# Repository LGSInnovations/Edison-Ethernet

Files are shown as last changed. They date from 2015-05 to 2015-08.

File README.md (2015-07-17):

Edison Ethernet Block
=====================

This project gives the Intel Edison ethernet capibility in applications where wired connections are necessary or more reliable.

Currently, there are two common Linux distros used on the Intel Edison: Yocto Linux and Ubilinux. The Edison Ethernet project has support for both and is created from forking those distros.

## Distro Support ##

We currently support a Debian based distro, based on Ubilinux, and the Yocto distro. Both are built with the Yocto 3.10 kernel, bitbaked with driver support for the LAN9512/SMSC95xx USB-to-Ethernet chip.

#### Ubilinux/Debian ####

Popular for its familiar package manager (`apt-get`), this build has support for the Edison Ethernet block as well as support for MAC spoofing using a tool called [macchanger](https://github.com/alobbs/macchanger).

#### Yocto ####

This Linux distro is great for lightweight projects as it has a rootfs size of about 500MB. Although it has support for the Edison Ethernet block, it does not currently have easy support for MAC spoofing through macchanger.

## Installation and Setup ##

To start using the Edison Ethernet block, there are four options, increasing in time/difficulty:

1. Download the binary release of the `smsc95xx.ko` driver and add it to your kernel modules.
2. Download pre-packaged images of this project ready to flash with the smsc95xx.ko module baked in.
3. Clone the Edison-Ethernet git project to avoid using bitbake, but still allowing you flexibility to add/remove files from the rootfs. Build the debian or yocto image and then flash using `./flashall.sh` such as illustrated at the end of the guide [here](https://github.com/LGSInnovations/Edison-Ethernet/blob/master/guides/customize-yocto-kernel.md)
4. Build from source using `bitbake` and `menuconfig` and flash your device using `./flashall.sh`.

#### Option 1 - Binary Release ####

Download the release corresponding to your board. Extract the files.

Inside the release, there is a directory called `modules`. You'll find different kernel versions inside. To know which kernel module to install on your Edison, run `uname -r` and pick the corresponding directory inside the release. If your kernel version is not available, create an issue and we will release one for that version. You can also make your own by following [these](guides/version-magic-error.md) instructions.

Once you know which kernel version to use, follow [these](guides/installation.md) instructions to copy and install on your Edison.

#### Option 2 - Pre-packed Images ####

Download the release corresponding to your board. Extract the files.

Inside the release, there is a directory called `images`. You'll find two tarballs: `yocto.tar.gz` and `debian.tar.gz`. Extract your choice of distro and use `sudo ./flashall.sh` as normal.

#### Option 3 - Leverage This Project ####

See *Contributing to this Project* below.

#### Option 4 - Build from Source ####

Follow [these](guides) instructions. *Be aware that this will take at least 5+ hours.*

## Contributing to this Project ##

We use Git Submodules in our repo, if you've never used that tool before, make sure to read about it [here](https://git-scm.com/book/en/v2/Git-Tools-Submodules).

#### Development Environment ####

All developent must be on a Linux machine. Because of the naming convention of files in the decompressed rootfs of Linux, Mac OS and Windows will groan about invalid file names. We use [Ubuntu 14.04.02](http://releases.ubuntu.com/14.04/) for our host environment.

#### Getting the Source ####

Source code / files can be cloned as follows:

```bash
git clone --recursive https://github.com/LGSInnovations/Edison-Ethernet.git # The '--recursive' flag will also clone the submodules 
```

#### Packaging Your Changes ####

After you have changed things to your liking, use the `package.sh` script in `Edison-Ethernet/src/` to package your `edison-image-edison.ext4` rootfs so you can run `sudo ./flashall.sh`. Make sure that you have pulled in the latest changes in the `edison-debain-image` and/or `edison-yocto-image` submodules.

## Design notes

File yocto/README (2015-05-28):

This tutorial is to help build the full yocto kernel for the Intel Edison.  It is largely based on work done by
Shawn Hymel at: http://shawnhymel.com/585/creating-a-custom-linux-kernel-for-the-edison/

This step-by-step assumes you are on some newer version of Ubuntu, preferably 14.04 forward with access to the
internet and access to apt repositories.

Setup your environment:
sudo apt-get install build-essential git diffstat gawk chrpath texinfo libtool gcc-multilib

sudo apt-get install libqt4-core:i386 ligqt4-gui:i386

Setup git (if not already setup);
git config --global user.email "you@example.com"
git config --global user.name "Your Name"

1) Get the file at: http://downloadmirror.intel.com/24910/eng/edison-src-ww18-15.tgz
--> At a shell execute:  wget http://downloadmirror.intel.com/24910/eng/edison-src-ww18-15.tgz
--> You can also find the file at: https://downloadcenter.intel.com/SearchResult.aspx?lang=eng&keyword=edison
--> The file will likely be called edison-src-ww18-15.tgz

2) Once the file is downloaded extract the contents to your preferred workspace.
--> cd ~
--> tar xvzf edison-src-ww18-15.tgz

3) Go into the directory
--> cd ~/edison-src

Inside ~/edison-src should have a structure of:
-----------------------------------------------
you@yourcomputer:~ l
Makefile -> meta-intel-edison/utils/Makefile.mk
meta-intel-edison/
-----------------------------------------------

4) Setup the build tree by pulling source from remote repos
--> make setup

Inside ~/edison-src should now have a structure of:
bbcache
Makefile -> meta-intel-edison/utils/Makefile.mk
meta-intel-edison/
out/
pub/

5) source the shell environment [note this is for 64-bit linux builds!]
--> cd ~/edison-src/out/linux64
--> source poky/oe-init-build-env

* Some systems (mostly those behind a firewall) will have problems fetching some packages.  They are on the
github repo.  Download the directory and move the files to edison-src/bbcache/downloads.  make sure to return
to the right directory before baking your bits.

An example might be:
cp ~/Downloads/Edison-Ethernet/packages/* ~/edison-src/bbcache/downloads/
NOTE: Remove the README

6) bitbake your shiny new edison image.  This could take hours the first time.
--> bitbake edison-image

7) Configure the kernel with your new feature
--> bitbake linux-yocto -c menuconfig

8) use the menuconfig to add the LAN9512 that you need, or copy the .config file from the github repo.
If using the menuconfig you can navigate to the below <ESC> <ESC> goes back, <ENTER> goes forward, <SPACE>
selects.

Device Drivers --->
	[*] Network Device Support --->
		USB Network Adapters --->
			< >SMSC LAN95XX based USB 2.0 10/100 ethernet devices
		
Press <<space>> until you see a <*> for the SMSC LAN95XX. Save the configuration.

BTW, while you're in there you can add I2C support:
Device Drivers --->
	-*- I2C support --->
		I2C Hardware Bus support --->
			[ ] PMIC I2C Adapter

Press <<space>> until you see a <*> for the PMIC I2C Adapter. Save the configuration.

Exit out.

--> cp edison-src/out/linux64/build/tmp/work/edison-poky-linux/linux-yocto/3.10.17+gitAUTO*/linux-edison-standard-build/.config \\
	edison-src/meta-intel-edison/meta-intel-edison-bsp/recipes-kernel/linux/files/defconfig
	
9) bake your edison again
--> cd ~/edison-src/out/linux64
--> source poky/oe-init-build-env
--> bitbake edison-image

10) use your favorite text editor to edit postBuild.sh to the following:

line 9: build_dir=$top_repo_dir/out/linux64/build

or

execute the existing postBuild.sh with an argument that is the full path to the build dir

edison-src/meta-intel-edison/utils/flash/postBuild.sh edison-src/out/linux64/build

11) Your files will be ready in edison-src/out/linux64/build/toFlash

12) The edison kernel is in edison-image-edison.hddimg

13) If using ubilinux download their setup from: http://www.emutexlabs.com/ubilinux
--> Pick the ubilinux for Intel Edison or
--> wget http://www.emutexlabs.com/files/ubilinux/ubilinux-edison-150309.tar.gz

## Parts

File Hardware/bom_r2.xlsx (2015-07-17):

Qty | Value | Device | Package | Parts | Description | MF | MPN | Digikey Part Number | Mouser Part Number | Newark Part Number | URL | Price ea. | Price ea. Order | Final order qty
2 | 0 Ohm | R-US_R1210 | R1210 | R10, R16 | RESISTOR, American symbol | Vishay | CRCW12100000Z0EA |  |  | 72M6870 | http://www.newark.com/vishay-dale/crcw12100000z0ea/resistor-chip-jumper-zero-ohm/dp/72M6870?ost=72M6870 | 0.248 | 0.496 | 10
1 | 0.01uF | C-USC0603K | C0603K | C18 | CAPACITOR | AVX | 06035C103KAT2A |  |  | 36K3729 | http://www.newark.com/avx/06035c103kat2a/ceramic-capacitor-0-01uf-50v-x7r/dp/36K3729?ost=36K3729 | 0.002 | 0.002 | 5
1 | 0.022uF | C-USC0805 | C0805 | C23 | CAPACITOR | AVX | 08055C223KAT2A |  |  | 35K2132 | http://www.newark.com/avx/08055c223kat2a/ceramic-capacitor-0-022uf-50v/dp/35K2132?ost=35K2132 | 0.162 | 0.162 | 5
15 | 0.1uF | C-USC0402K | C0402K | C1, C2, C3, C4, C5, C6, C7, C8, C9, C10, C11, C12, C14, C15, C16 | CAPACITOR | AVX | 0402ZD104KAT2A |  |  | 96M1117 | http://www.newark.com/avx/0402zd104kat2a/ceramic-capacitor-0-1uf-10v-x5r/dp/96M1117?ost=96M1117 | 0.006 | 0.09 | 75
2 | 1uF | C-USC0402K | C0402K | C13, C27 | CAPACITOR | AVX | 0402ZD105KAT2A |  |  | 06M4041 | http://www.newark.com/avx/0402zd105kat2a/ceramic-capacitor-1uf-10v-x5r/dp/06M4041?ost=06M4041 | 0.24 | 0.48 | 10
1 | 10 Ohm | R-US_R0402 | R0402 | R9 | RESISTOR | Multicomp | MC00625W0402110R |  |  | 58K4201 | http://www.newark.com/multicomp/mc00625w0402110r/resistor-10r-0-063w-1-0402/dp/58K4201?ost=58K4201 | 0.002 | 0.002 | 5
2 | 10K | R-US_R0603 | R0603 | R1, R4, R17 | RESISTOR | Multicomp | MCMR06X1002FTL |  |  | 86T3506 | http://www.newark.com/multicomp/mcmr06x1002ftl/resistor-ceramic-10k-0-1w-1/dp/86T3506 | 0.016 | 0.032 | 10
1 | 12.4K | R-US_R0603 | R0603 | R3 | RESISTOR | Multicomp | MC0063W0603112K4 |  |  | 94W4696 | http://www.newark.com/multicomp/mc0063w0603112k4/resistor-12k4-0-063w-1-0603/dp/94W4696?ost=94W4696 | 0.001 | 0.001 | 5
1 | 56K | R-US_R0 | R0603 | R15 | RESISTOR | Panasonic | ERJ-P03F5602V |  |  | 05X8647 | http://www.newark.com/panasonic-electronic-components/erj-p03f5602v/thick-film-resistor-56kohm-1-0603/dp/05X8647 | 0.031 | 0.031 | 5
1 | 12K | R-US_R0603 | R0603 | R2 | RESISTOR | Multicomp | MC0603SAF1202T5E |  |  | 79M5909 | http://www.newark.com/multicomp/mc0603saf1202t5e/thick-film-resistor-12kohm-100mw/dp/79M5909?ost=79M5909 | 0.067 | 0.067 | 5
1 | 150uF | CAP_POLE | PANASONIC_E | C26 | Capacitor Polarized | Panasonic | EEH-ZC1V151P |  |  | 91T4915 | http://www.newark.com/panasonic-electronic-components/eeh-zc1v151p/aluminum-electrolytic-capacitor/dp/91T4915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 | 3.39 | 3.39 | 5
4 | 15pF | C-USC0402 | C0402 | C19, C20, C21, C22 | CAPACITOR | AVX | 04025A150JAT2A |  |  | 96M1134 | http://www.newark.com/avx/04025a150jat2a/ceramic-capacitor-15pf-50v-c0g/dp/96M1134?ost=96M1134 | 0.002 | 0.008 | 20
1 | 1M | R-US_R0402 | R0402 | R14 | RESISTOR | Multicomp | MC00625W040211M |  |  | 58K4211 | http://www.newark.com/multicomp/mc00625w040211m/resistor-1m-0-063w-1-0402/dp/58K4211?ost=58K4211 | 0.001 | 0.001 | 5
2 | 2.0A 120Ohm | L-US0603 | L0603 | L1, L2 | Ferrite Bead | Murata | BLM18PG121SN1D |  |  | 73M9109 | http://www.newark.com/murata/blm18pg121sn1d/ferrite-bead-120-ohm-2a-0603/dp/73M9109?ost=73M9109 | 0.044 | 0.088 | 10
1 | 25MHz | CRYSTAL-GROUNDED | CRYSTAL-SMD-5X3 | U$1 | 25MHz Crystal | Abracon | ABM3B-25.000MHZ-B2-T |  |  | 13J1745 | http://www.newark.com/abracon/abm3b-25-000mhz-b2-t/crystal-25mhz-18pf-5-x-3-2mm/dp/13J1745?ost=13J1745 | 0.691 | 0.691 | 5
3 | 330 Ohm | R-US_R0402 | R0402 | R11, R12, R13 | RESISTOR | Multicomp | MC00625W04021330R |  |  | 58K4323 | http://www.newark.com/multicomp/mc00625w04021330r/resistor-330r-0-063w-1-0402/dp/58K4323?ost=58K4323 | 0.067 | 0.201 | 15
2 | 33pF | C-USC0402 | C0402 | C24, C25 | CAPACITOR | AVX | 04025A330JAT2A |  |  | 96M1150 | http://www.newark.com/avx/04025a330jat2a/ceramic-capacitor-33pf-50v-c0g/dp/96M1150?ost=96M1150 | 0.11 | 0.22 | 10
1 | 4.7uF | C-USC0603K | C0603K | C17 | CAPACITOR | AVX | 06036D475KAT2A |  |  | 96M1295 | http://www.newark.com/avx/06036d475kat2a/ceramic-capacitor-4-7uf-6-3v-x5r/dp/96M1295?ost=96M1295 | 0.013 | 0.013 | 5
4 | 49.9 Ohm | R-US_R0402 | R0402 | R5, R6, R7, R8 | RESISTOR | Multicomp | MC0402WGF499JTCE |  |  | 79M5889 | http://www.newark.com/multicomp/mc0402wgf499jtce/thick-film-resistor-49-9-ohm-63mw/dp/79M5889?ost=79M5889 | 0.067 | 0.268 | 20
1 | EDISON_CONNECTOR_FULLHEADER | Edison Plug (Male) | DF40C-70DP-0.4(51) | U4 |  | Hirose | DF40C-70DP-0.4V(51) | H11630CT-ND |  |  | http://www.digikey.com/product-search/en?KeyWords=H11630CT-ND&WT.z_header=search_go | 1.44 | 1.44 | 5
1 | EDISON_CONNECTOR_FULLMOUNTING_HOLES | Hirose Socket (Female) | DF40C(2.0)-70DS-0.4V(51) | U1 |  | Hirose | DF40C(2.0)-70DS-0.4V(51) | H11908CT-ND |  | 68X2583 | http://www.digikey.com/product-search/en?KeyWords=H11908CT-ND&WT.z_header=search_go | 1.37 | 1.37 | 5
1 | Green LED | LEDCHIP-LED0805 | CHIP-LED0805 | LED1 | LED | Lite-On | LTST-C170GKT/SML-LX0805SGC-TR | 160-1179-1-ND |  | 09J9138 | http://www.newark.com/lumex/sml-lx0805sgc-tr/led-green-1-25mm-x-1-4mm-15mcd/dp/09J9138?ost=09J9138 | 0.093 | 0.093 | 5
1 | J1011F01P | J1011F01P | J1 | X1 | PULSEJACK (TM) 1x1 Tab-UP RJ45 with Integrated Magnetics | Pulse Engineering | J1011F01PNL | 553-1350-ND |  |  | http://www.digikey.com/product-search/en?KeyWords=553-1350-ND&WT.z_header=search_go | 7.87 | 7.87 | 5
1 | LAN9512-JZX | LAN9512-JZX | QFN50P900X900X100-65N | U2 | IC, USB2 - ENET CNTRL 2-PORT HUB, 64VQFN | Microchip/SMSC | LAN9512-JZX | 638-1086-ND |  | 66W1988 | http://www.newark.com/microchip/lan9512-jzx/usb-hub-ethernet-controller-100mbps/dp/69W9521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 | 4.72 | 4.72 | 5
1 | MAX4495AAUT | MAX4995 | SOT23 | U3 | IC, Current-limited USB control switch | Maxim | MAX4995A |  | 700-MAX4995AAUTT |  | http://www.mouser.com/ProductDetail/Maxim-Integrated/MAX4995AAUT+T/ | 2.75 | 2.75 | 5
1 | USB-A-S | USB-A-S | USB-A-S | JP2, | USB Connectors | FCI | 87583-2010BLF |  |  | 31M6798 | http://www.newark.com/fci/87583-2010blf/usb-2-0-type-a-recetpacle-smt/dp/31M6798?ost=31M6798 | 0.696 | 0.696 | 5
 |  |  |  |  |  |  |  |  |  |  |  | Price Ea. Order: | 25.182
 |  |  |  |  |  |  |  |  |  |  |  | # of Orders: | 5
 |  |  |  |  |  |  |  |  |  |  |  | Final Order Cost: | 125.91

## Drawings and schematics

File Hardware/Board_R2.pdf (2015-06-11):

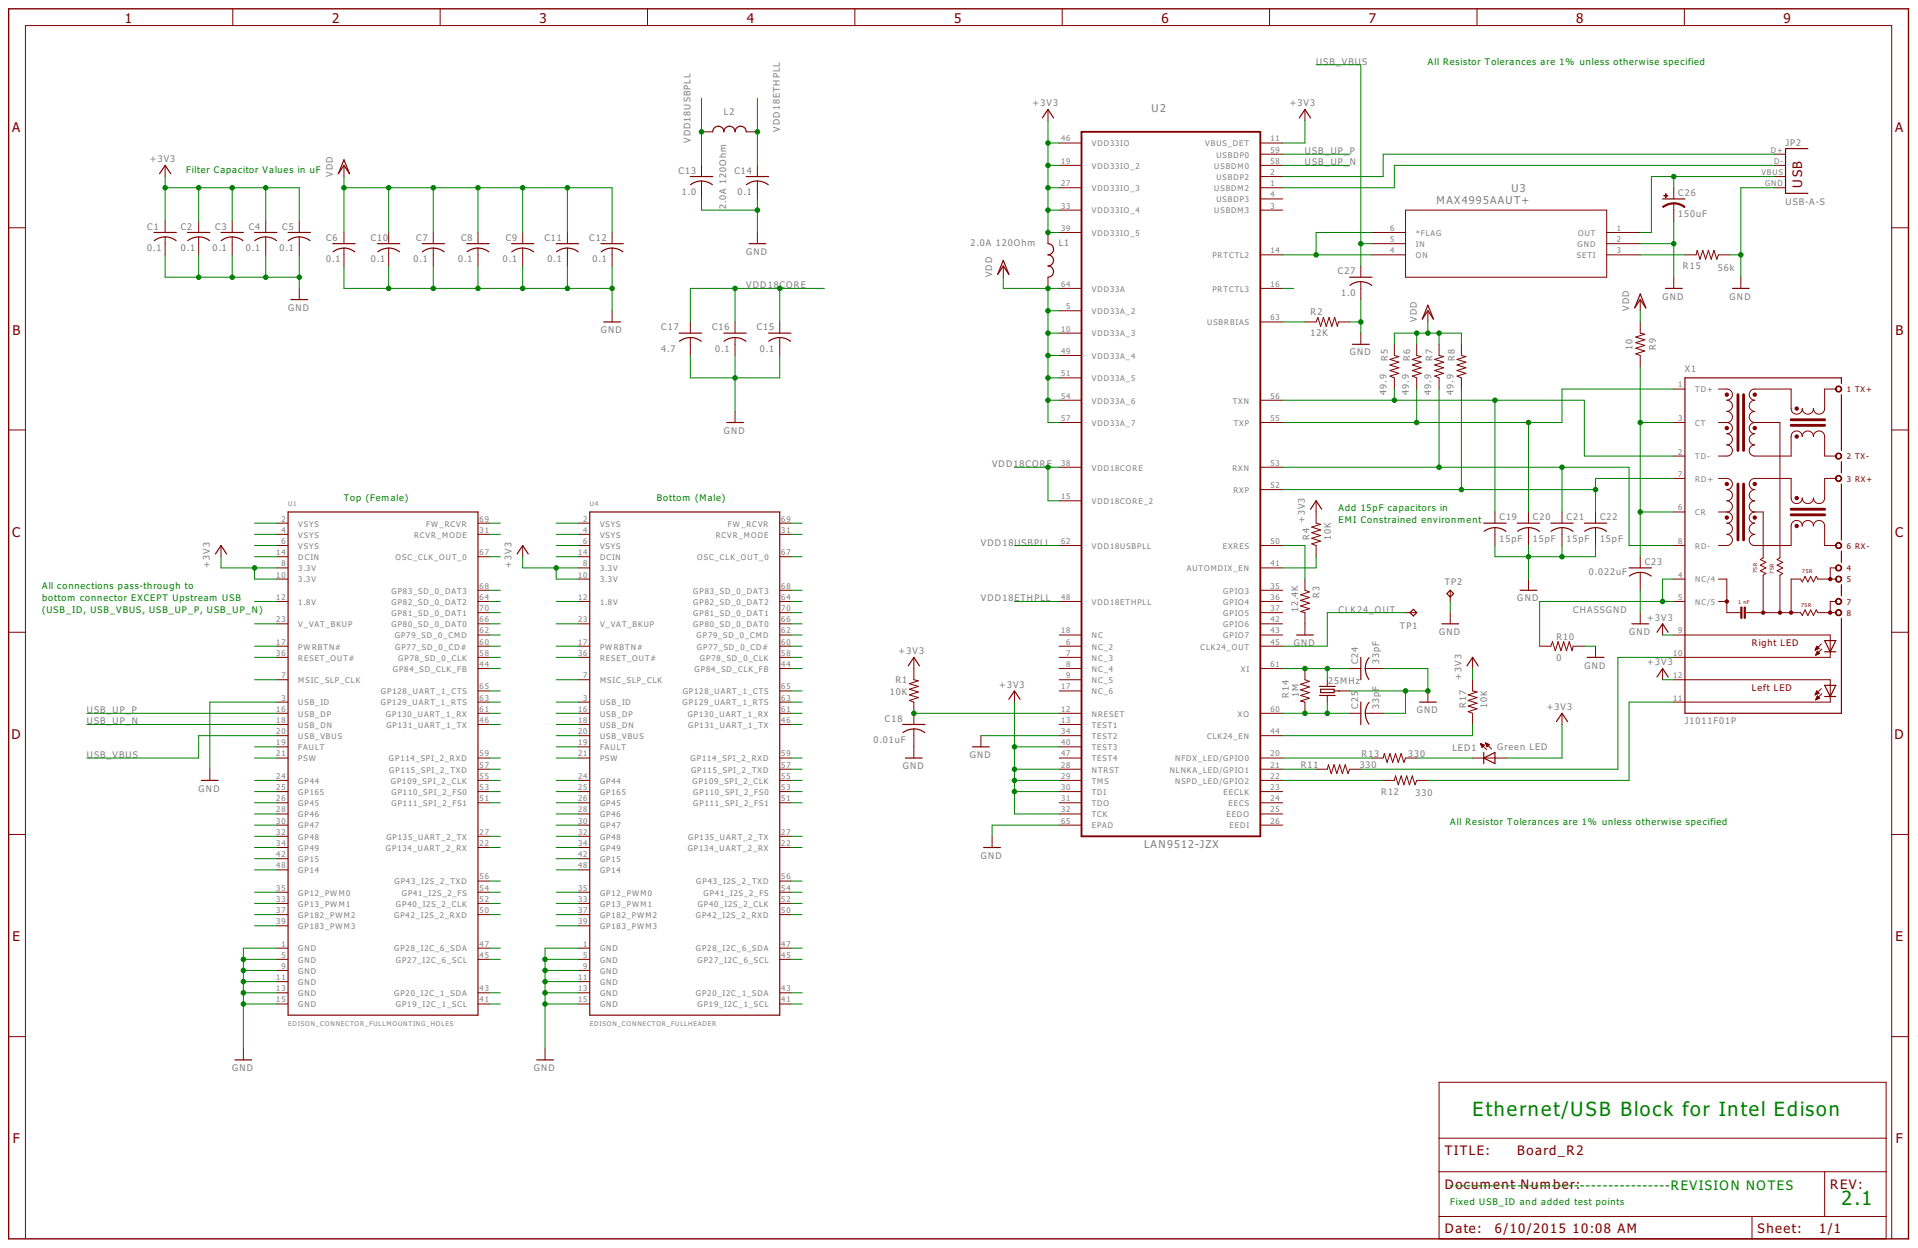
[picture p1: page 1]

All Resistor Tolerances are 1% unless otherwise specified

Filter Capacitor Values in uF

33 | 4 3 USBDP3

Add 15pF capacitors in EMI Constrained environment All connections pass-through to bottom connector EXCEPT Upstream USB

Ethernet/USB Block for Intel Edison

REV: TITLE: Document Number: Board_R2

---------------------------------------REVISION NOTES Fixed USB_ID and added test points | 2.1

Date: 6/10/2015 10:08 AM | Sheet: 1/1

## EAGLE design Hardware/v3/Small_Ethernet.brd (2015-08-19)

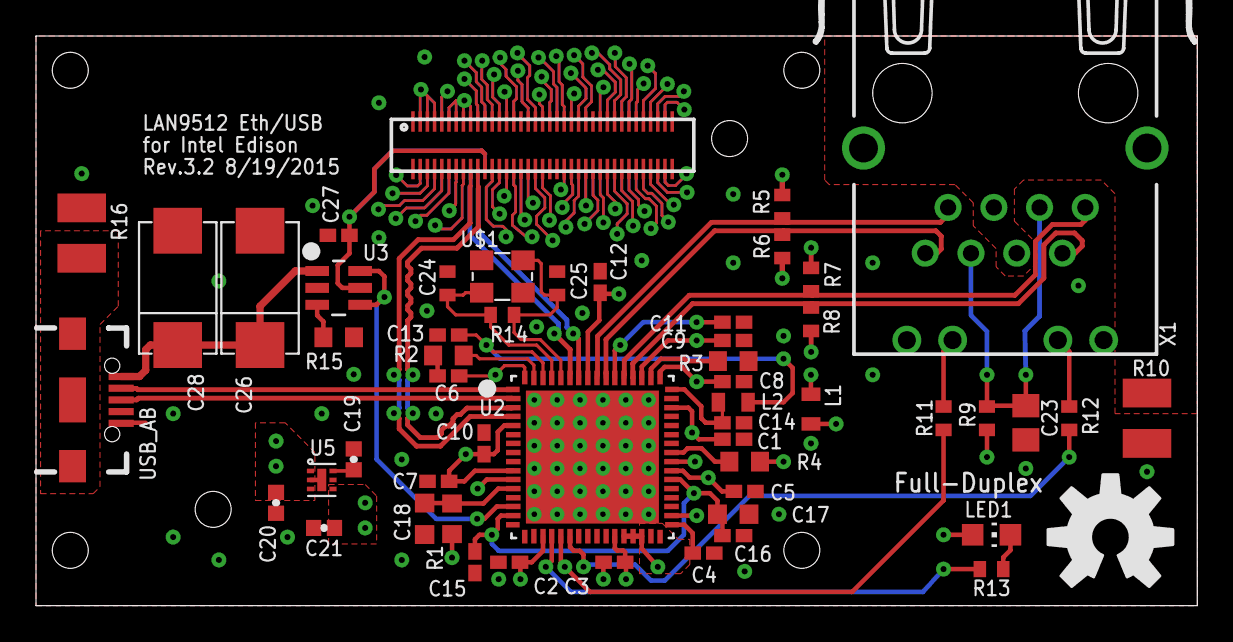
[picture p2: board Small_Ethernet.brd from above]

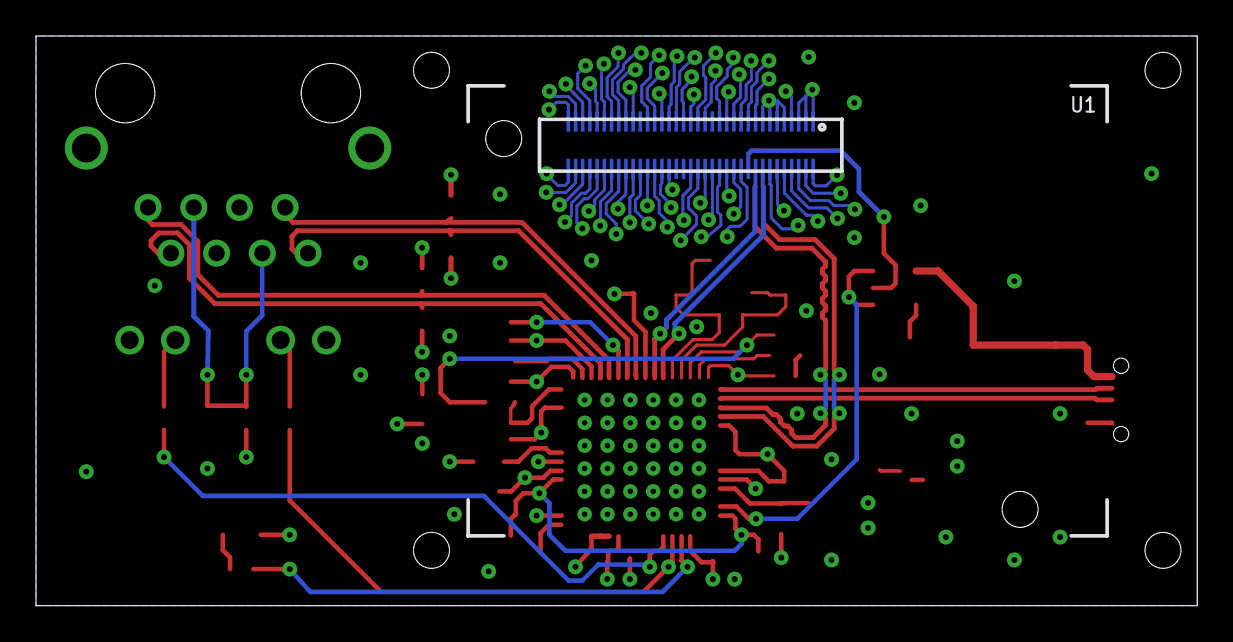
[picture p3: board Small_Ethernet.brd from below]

Board: 4 copper layers, 64.5 x 31.6 mm, 55 parts (2 on the bottom side), 90 nets.

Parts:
C1, C2, C3, C4, C5, C6, C7, C8, C9, C10, C11, C12, C14, C15, C16: 0.1; C0402K
C13, C27: 1.0; C0402K
C17: 4.7; C0603K
C18: 0.01uF; C0603K
C19: .1uF; 0402-CAP
C20, C21: 1uF; 0402-CAP
C23: 0.022uF; C0805
C24, C25: 33pF; C0402
C26, C28: CAP-2917
E$2: OSHW-LOGO-L
L1, L2: 2.0A 120Ohm; L0603
LED1: Green LED; CHIP-LED0805
R1, R4: 10K; R0603
R2: 12K; R0603
R3: 12.4K; R0603
R5, R6, R7, R8: 49.9; R0402
R9: 10; R0402
R10, R16: 0; R1210
R11, R12, R13: 330; R0402
R14: 1M; R0402
R15: 56k; R0603
U1: EDISON_CONNECTOR_FULLMOUNTING_HOLES; EDISON_DAUGHTER
U2: LAN9512-JZX; QFN50P900X900X100-65N
U3: MAX4995AAUT+; 21-0058I
U4: EDISON_CONNECTOR_FULLHEADER; DF40C-70DP-0.4(51)
U5: 6-UFDFN
U$1: SMDCRYSTAL_3.2X2.5
USB_AB: USB-AB-MICRO-SMD_V03
X1: J1011F01P; J1

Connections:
BYP: C19.1, U5.P6
DSUSB_N: U2.1, USB_AB.D-1
DSUSB_P: U2.2, USB_AB.D+1
GND: C1.2, C2.2, C3.2, C4.2, C5.2, C6.2, C7.2, C8.2, C9.2, C10.2, C11.2, C12.2, C13.2, C14.2, C15.2, C16.2, C17.2, C18.2, C19.2, C20.1, C21.2, C23.2, C24.2, C25.2, C26.NEG, C27.2, C28.NEG, R2.2, R3.2, R10.2, R15.1, R16.2, U1.1, U1.3, U1.5, U1.9, U1.11, U1.13, U1.15, U2.34, U3.2, U4.1, U4.3, U4.5, U4.9, U4.11, U4.13, U4.15, U5.GND, U5.P2, U$1.P2_GND, U$1.P4_GND, USB_AB.GND1
GP28_I2C_6_SDA: U1.47, U4.47
unnamed: C13.1, L2.1, U2.62
unnamed: C14.1, L2.2, U2.48
unnamed: C15.1, C16.1, C17.1, U2.15, U2.38
unnamed: R2.1, U2.63
unnamed: C18.1, R1.1, U2.12
unnamed: R3.1, U2.50
unnamed: R4.1, U2.41
unnamed: C23.1, R9.1, X1.3, X1.6
unnamed: R11.2, U2.21
unnamed: R11.1, X1.10
unnamed: R12.1, X1.11
unnamed: R12.2, U2.22
unnamed: LED1.C, R13.1
unnamed: R13.2, U2.20
unnamed: C24.1, R14.1, U2.61, U$1.P1_I/O
unnamed: C25.1, R14.2, U2.60, U$1.P3_O/I
unnamed: U2.14, U3.4, U3.6
unnamed: R15.2, U3.3
P7: U1.7, U4.7
P12: U1.12, U4.12
P14: U1.14, U4.14
P17: U1.17, U4.17
P19: U1.19, U4.19
P21: U1.21, U4.21
P22: U1.22, U4.22
P23: U1.23, U4.23
P24: U1.24, U4.24
P25: U1.25, U4.25
P26: U1.26, U4.26
P27: U1.27, U4.27
P28: U1.28, U4.28
P30: U1.30, U4.30
P31: U1.31, U4.31
P32: U1.32, U4.32
P33: U1.33, U4.33
P34: U1.34, U4.34
P35: U1.35, U4.35
P36: U1.36, U4.36
P37: U1.37, U4.37
P39: U1.39, U4.39
P41: U1.41, U4.41
P42: U1.42, U4.42
P43: U1.43, U4.43
P44: U1.44, U4.44
P45: U1.45, U4.45
P46: U1.46, U4.46
P48: U1.48, U4.48
P50: U1.50, U4.50
P51: U1.51, U4.51
P52: U1.52, U4.52
P53: U1.53, U4.53
P54: U1.54, U4.54
P55: U1.55, U4.55
P56: U1.56, U4.56
P57: U1.57, U4.57
P58: U1.58, U4.58
P59: U1.59, U4.59
P60: U1.60, U4.60
P61: U1.61, U4.61
P62: U1.62, U4.62
P63: U1.63, U4.63
P64: U1.64, U4.64
P65: U1.65, U4.65
P66: U1.66, U4.66
P67: U1.67, U4.67
P68: U1.68, U4.68
P69: U1.69, U4.69
P70: U1.70, U4.70
RX_N: R8.1, U2.52, X1.7
RX_P: R7.1, U2.53, X1.8
S$5: U1.10, U4.10
S$6: U1.8, U4.8
SHLD: R10.1, X1.4, X1.5, X1.M1, X1.M2
TX_N: R5.1, U2.56, X1.2
TX_P: R6.1, U2.55, X1.1
USBSHLD: R16.1, USB_AB.SHIELD1, USB_AB.SHIELD2, USB_AB.SHIELD3
USBUP_N: U1.18, U2.58
USBUP_P: U1.16, U2.59
USB_D_N: U2.3, U4.18
USB_D_P: U2.4, U4.16
USB_VBUS: C27.1, U1.20, U3.5, U4.20
VBUS_OUT: C26.POS, C28.POS, U3.1, USB_AB.VBUS1
VDD3IO: C1.1, C2.1, C3.1, C4.1, C5.1, C21.1, L1.1, LED1.A, R1.2, R4.2, U2.11, U2.19, U2.27, U2.28, U2.29, U2.30, U2.32, U2.33, U2.39, U2.40, U2.46, U5.P4, X1.9, X1.12
VDD33A: C6.1, C7.1, C8.1, C9.1, C10.1, C11.1, C12.1, L1.2, R5.2, R6.2, R7.2, R8.2, R9.2, U2.5, U2.10, U2.49, U2.51, U2.54, U2.57, U2.64
VSYS: C20.2, U1.2, U1.4, U1.6, U4.2, U4.4, U4.6, U5.P1, U5.P3

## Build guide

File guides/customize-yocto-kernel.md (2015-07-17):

Customizing the Yocto Kernel
============================

This tutorial is to help build the full Yocto Kernel for the Intel Edison.  It is largely based on work done by [Shawn Hymel](http://shawnhymel.com/585/creating-a-custom-linux-kernel-for-the-edison/).

This step-by-step assumes you are on some newer version of Ubuntu as the host machine, preferably 14.04 forward with access to the internet and access to apt repositories.

**Note:** The build part of this tutorial can take up to 4 hours.

##Setting Up Your Environment##

1. Install Dependencies:
	```bash
	sudo apt-get install build-essential git diffstat gawk chrpath texinfo libtool gcc-multilib libsdl1.2-dev dfu-util libqt4-core:i386 libqt4-gui:i386
	```

2. Setup git (if not already setup):
	```bash
	git config --global user.email "you@example.com"
	git config --global user.name "Your Name"
	```

##Building the Yocto Kernel:##

1. Get the file at: http://downloadmirror.intel.com/24910/eng/edison-src-ww18-15.tgz
	- At a shell execute:  `wget http://downloadmirror.intel.com/24910/eng/edison-src-ww18-15.tgz` in your home folder.
	- You can also find the file at: https://downloadcenter.intel.com/SearchResult.aspx?lang=eng&keyword=edison
	- The file will likely be called `edison-src-ww18-15.tgz`

2. Once the file is downloaded extract the contents to your preferred workspace.
	```bash
	cd ~
	tar xvzf edison-src-ww18-15.tgz
	```

3. Go into the directory `~/edison-src`:
	```bash
	cd ~/edison-src
	```

 It should have a structure of:
	```bash
	.
	+-- Makefile -> meta-intel-edison/utils/Makefile.mk
	+-- meta-intel-edison/
	```

4. Setup the build tree by pulling source from remote repos
	```bash
	make setup
	```

 Now, `~/edison-src` should now have a structure of:
	```bash
	.
	+-- bbcache/
	+-- Makefile -> meta-intel-edison/utils/Makefile.mk
	+-- meta-intel-edison/
	+-- out/
	+-- pub/
	```

 *5. Some systems (mostly those behind a firewall) will have problems fetching some packages.  They are on in this repo at `Edison-Ethernet/packages/`.  Download the directory and move the files to `~/edison-src/bbcache/downloads`.*

 An example of downloading these packages from the repo might be:
	```bash
	cp ~/Edison-Ethernet/packages/* ~/edison-src/bbcache/downloads/
	```
	**NOTE**: Remove the README (`rm ~/edison-src/bbcache/downloads/README`)

6. bitbake your shiny new edison image.  **This could take hours the first time.** This can be done in two ways:
	1. Sourcing the shell environment and then running `bitbake`.

		 ```bash
		 cd ~/edison-src/out/linux64
		 source poky/oe-init-build-env
		 ```
		 This will automatically put you in the `~/edison-src/build` directory. Then run:
		 ```bash
		 bitbake edison-image
		 ```
	2. Using the Makefile. *(make sure you are in the `~/edison-src` directory).*

		 **Option 2:** 
		 ```bash
		 make image
		 ```

		 **NOTE**: If your bitbake fails, (possibly with `swig-3.0.5` not being found) just run `make image` again, and it will start from there.

After a number of hours (e.g., 4 or 5) come back to configure the kernel.

----------------------------------------------------------------------

##Configuring the Kernel##

1. Configure the kernel with your new feature (this may take some time):
	```bash
	source ~/edison-src/out/linux64/poky/oe-init-build-env
	bitbake linux-yocto -c menuconfig
	```

2. Use the `menuconfig` to add the LAN9512 that you need, or copy the `.config` file from this repo. If using the `menuconfig` you can navigate to the below <kbd>esc</kbd> <kbd>esc</kbd> goes back, <kbd>enter</kbd> goes forward, <kbd>space</kbd> selects.

	```
	Device Drivers --->
		[*] Network Device Support --->
			USB Network Adapters --->
				< >SMSC LAN95XX based USB 2.0 10/100 ethernet devices
	```
		
 	Press <kbd>space</kbd> until you see a <*> for the SMSC LAN95XX. Save the configuration.

	Also, while you're in there you can add I2C support:
	```
	Device Drivers --->
		-*- I2C support --->
			I2C Hardware Bus support --->
				[ ] PMIC I2C Adapter
	```

	Press <kbd>space</kbd> until you see a <*> for the PMIC I2C Adapter. Save the configuration.

	Exit out.
	```bash
	cp edison-src/out/linux64/build/tmp/work/edison-poky-linux/linux-yocto/3.10.17+gitAUTO*/linux-edison-standard-build/.config \\
	edison-src/meta-intel-edison/meta-intel-edison-bsp/recipes-kernel/linux/files/defconfig
	```
	
3. Bake your Edison again, either using `make` or `bitbake` as above.
	```
	cd ~/edison-src
	make
	```

	or

	```bash
	cd ~/edison-src/out/linux64
	source poky/oe-init-build-env
	bitbake edison-image
	```

4. Run the `postBuild.sh` script to clean up the `toFlash` directory as follows:

	```bash
	~/edison-src/meta-intel-edison/utils/flash/postBuild.sh ~/edison-src/out/linux64/build
	```

	Alternatively, you can use your favorite text editor to edit `postBuild.sh` to the following:
	```bash
	line 9: build_dir=$top_repo_dir/out/linux64/build
	```

	And then execute the `postBuild.sh` script without the build directory argument:
	```bash
	~/edison-src/meta-intel-edison/utils/flash/postBuild.sh
	```

5. Your files will be ready in `~/edison-src/out/linux64/build/toFlash`.

6. You may now either flash your Edison with Yocto and follow the Yocto Network Interface setup, or you can use the Yocto kernel in the Ubilinux distro to give yourself a more fleshed out Linux distro with `apt-get`.

7. Flashing your Edison with Yocto:
	
	```bash
	sudo ~/edison-src/out/linux64/build/toFlash/flashall.sh
	```

	And then plug your Edison in via the OTG port of the SparkFun base-board.

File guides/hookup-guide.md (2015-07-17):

Hookup Guide for LAN9512 Ethernet block
=======================================

##Plug in the Board##
Once you have [installed support for the SMSC LAN9512](https://github.com/LGSInnovations/Edison-Ethernet/blob/master/README.md) on your Intel Edison, you may connect the Edison blocks together. While connecting and using the hardware, keep the following points in mind: 
* When operating properly, the "Full-Duplex" LED on the Ethernet block will be illuminated. 
* Blocks can be stacked without any sort of mounting hardware. However, this can cause undue mechanical stress on the connectors. To alleviate this, use hardware such as that found in the [Sparkfun Edison Hardware Pack](https://www.sparkfun.com/products/13187) to securely mount your Edison blocks.
* The SMSC LAN9512 communicates with the Intel Edison over USB-OTG. Do not connect any other blocks that use the Intel Edison's USB-OTG capability. Disconnect the Ethernet block when flashing your Edison's firmware. 
* The Ethernet block cannot power the Edison. A power source such as the [Sparkfun Base Block](https://www.sparkfun.com/products/13045) in your block stack is required. 
* If an overcurrent condition is detected in a device connected to the downstream USB port on the Ethernet Block, the port will be shut down. Usually, the port will reset itself after a few seconds. In some circumstances, you may need to completely power-down the Ethernet Block and re-apply power to reset the port. 
* Version 1.0 of the Ethernet block is too wide to accomodate a USB cable plugged into a board such as the Sparkfun Base Block if the Base Block and the Ethernet Block are right next to each other in your block stack. To remedy this, connect a block with no external connectors (such as an empty [Sparkfun GPIO block](https://www.sparkfun.com/products/13038)) between the Base Block and the Ethernet Block. 
* Version 1.0 of the Ethernet Block operates close to the maximum current supply capacity of the 3.3V rails of the Intel Edison. Use caution when connecting blocks that use the 3.3V rails and power them with an external 3.3V supply if possible.

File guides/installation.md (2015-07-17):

Installing the smsc95xx.ko Module
=================================

These steps can be used after (1) downloading the release binaries, or (2) building your own modules from source.

## Getting the Module to the Edison ##

There are three ways to get the module onto the Edison:

1. Use WiFi and `curl`
2. Use a USB drive.
3. Access the Edison's mass-storage. **[Yocto only!]**

#### Using WiFi ####

If not already done, enable Edison's WiFi using the appropriate guide:

+ [Yocto](https://software.intel.com/en-us/connecting-your-intel-edison-board-using-wifi)
+ [Debian](https://learn.sparkfun.com/tutorials/loading-debian-ubilinux-on-the-edison#enable-wifi)

Use a service such as [transfer.sh](https://transfer.sh/) to `curl` the `smsc95xx.ko` module from your host machine to the Intel Edison.

You should now have the `smsc95xx.ko` in your home folder.

#### USB Drive ####

Copy the `smsc95xx.ko` module from your host machine to a usb drive.

Use a guide (like [this](http://linuxconfig.org/howto-mount-usb-drive-in-linux) one) to mount the USB drive. 

*Remember that you might have to format the drive as FAT32 before you use it.*

#### Edison's Mass-Storage [Yocto only!] ####

This will only work for Yocto, but you can plug the Edison to your host machine through the OTG port and it will show up as a mass-storage device that you can drag the `smsc95xx.ko` file onto.

Then use these steps on your Edison to access the partition:

```bash
rmmod g_multi
mkdir /update
losetup -o 8192 /dev/loop0 /dev/disk/by-partlabel/update
mount /dev/loop0 /update
```

*see [this](https://communities.intel.com/message/253856#253856) answer*

## Installing the Module on the Edison ##

Now that you have the module on the Edison, we need to install it so the kernel knows where to find it.

Use the following commands:

```bash
# Create a logical place to store it in the kernel dir
mkdir -p /lib/modules/$(uname -r)/kernel/drivers/net/usb

# Move the module to that directory
mv smsc95xx.ko /lib/modules/$(uname -r)/kernel/drivers/net/usb/

# Probe all modules to generate the modules.dep and map files
# This allows you to run `modprobe smsc95xx` from anywhere.
# This also allows the system to bring up the LAN chip on boot.
depmod -a

# Enable the driver
modprobe smsc95xx
```

You should now see the `smsc95xx` module in the `lsmod` list.

Similarly, running `lsusb` should show something like:

```bash
Bus 001 Device 003: ID 0424:ec00 Standard Microsystems Corp. SMSC9512/9514 Fast Ethernet Adapter
Bus 002 Device 001: ID 1d6b:0003 Linux Foundation 3.0 root hub
Bus 001 Device 002: ID 0424:9512 Standard Microsystems Corp. LAN9500 Ethernet 10/100 Adapter / SMSC9512/9514 Hub
Bus 001 Device 001: ID 1d6b:0002 Linux Foundation 2.0 root hub
```

If the Ethernet is plugged in, you should see the Full-Duplex LED light up on the board.

## Setting up the Network Interface ##

Follow the appropriate guide to set up your Network Inferface:
	
+ [Yocto](yocto-network-setup.md)
+ [Debian](ubilinux-network-setup.md)

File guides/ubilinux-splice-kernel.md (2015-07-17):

Using the Customized Yocto Kernel in Ubilinux
=============================================

After having BitBaked the Yocto Kernel with SMSC LAN95XX driver support for the Ethernet block, you can take the Yocto kernel and its modules and splice them into the Ubilinux distro.

This allows you to use the LAN9512 Ethernet block with a Debian-based Linux distro, with better support for installing packages.

1. Download the Ubilinux distro from [here](http://www.emutexlabs.com/ubilinux). Choose the Intel Edison.
	- Alternatively, run `wget http://www.emutexlabs.com/files/ubilinux/ubilinux-edison-150309.tar.gz` on your Linux host machine.

2. Extract the archive with:
	
	```bash
	tar xvf ~/ubilinux-edison-150309.tar.gz
	cd ubilinux-150309/toFlash
	```

3. The Edison kernel is in `edison-image-edison.hddimg`, the filesystem is in `edison-image-edison.ext4`. Move the kernel (`*.hddimg`) out of the directory:

	```bash
	mv edison-image-edison.hddimg ../edison-image-edison.hddimg.ubi
	```

4. Copy the Yocto Edison kernel to here:

	```bash
	cp ~/edison-src/out/current/build/toFlash/edison-image-edison.hddimg .
	```

5. Next, you will need to mount the Ubilinux filesystem and replace its kernel modules with the Yocto kernel modules:

	```bash
	sudo mkdir /mnt/ubi
	sudo mount edison-image-edison.ext4 /mnt/ubi
	sudo rm -rf /mnt/ubi/lib/modules/3.10.17-yocto-standard-r2
	sudo cp -r ~/edison-src/out/current/build/tmp/work/edison-poky-linux/edison-image/1.0-r0/rootfs/lib/modules/* /mnt/ubi/lib/modules/
	sudo umount /mnt/ubi
	```
6. Now that you've copied the Yocto kernel and its modules, you can flash your Edison as follows:

	```bash
	cd ~/ubilinux-150309/toFlash
	sudo ./flashall.sh
	```

	And then plug your Edison in via the OTG port of the SparkFun base-board.

7. When booting on the Edison, make sure that all the kernel modules got loaded (there are about 5 of them), otherwise `lsmod` will return no modules, and `lsusb` will return `-99`. Note that the default password for the _root_ account is "edison."

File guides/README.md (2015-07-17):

Edison-Ethernet Guides
======================

These guides can be used for setting up various parts of the Edison-Ethernet project:

1. [Customizing the Yocto Kernel](customize-yocto-kernel.md), i.e., adding the SMSC95xx module.
2. [Using Ubilinux](ubilinux-splice-kernel.md) by splicing in the customized Yocto kernel.
3. Network setup: [Yocto](yocto-network-setup.md) and [Ubilinux](ubilinux-network-setup.md).
4. Misc: [Version Magic Error](version-magic-error.md) when installing kernel modules.
5. [Installing](installation.md) the SMSC95xx kernel module.
6. [Hardware Hookup Guide](hookup-guide.md)

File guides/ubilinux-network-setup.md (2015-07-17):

Setting up the Network Interface for Ubilinux with Yocto Kernel
===============================================================

This will walk you through bringing the ethernet block up on the Edison.

Follow these steps after `screen`'ing into your Edison from your host Linux machine, as described [here](https://software.intel.com/en-us/setting-up-serial-terminal-on-system-with-linux) (i.e., `sudo screen /dev/ttyUSB0 115200`).

1. Login to the edison as `root` with password `edison`.

2. Verify that your Edison sees the `eth0` interface by doing `ifconfig -a`. In `screen`, you can scroll by doing: <kbd>Ctrl</kbd>-<kbd>a</kbd> <kbd>esc</kbd> and then using the up/down arrow keys.

3. Add the `eth0` interface to the `/etc/network/interfaces` file:

	```bash
	vi /etc/network/interfaces
	```

	And add this to the file:

	```bash
	auto eth0
	iface eth0 inet dhcp
	```

	To enable DHCP on `eth0`.

4. Bring up the Ethernet block with: `ifup eth0`.

5. Run `ifconfig` again to get the IP address for `eth0`. Use that IP address to SSH into your edison, without having to use `screen`.

**Known Issue:** For some reason, the Edison will not switch into USB Host mode after a warm reboot (i.e., after running `reboot`). You must start cold by unplugging the Edison and turning it back on again. (For more info, see [here](https://communities.intel.com/thread/57209?start=0&tstart=0))

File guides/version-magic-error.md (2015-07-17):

Version Magic Error
===================

When building a kernel module, it is stampped with a version. The kernel employs a scheme called version magic to ensure that you are using the correct module version.

If the kernel version extensions are slightly different, the module will most likely work, you just have to rebuild the module with the correct target version.

Because Ubilinux and Yocto have different kernel version extensions, you will have to trick BitBake to create the correct module version. Below is a table with the Linux version and it's kernel version:

| Distro | Kernel Version |
| :--- |:--- |
| Release 2.1 Yocto complete image | 3.10.17-poky-edison+ |
| Release 2.1 Linux Source Files | 3.10.17-yocto-standard |
| Ubilinux "Wheezy", 150309 | 3.10.17-yocto-standard-r2 |

## Rebuilding the Right Version ##

To add a kernel module, you must build from source, using `bitbake linux-yocto -c menuconfig` to add in the necessary module.

You then have two options:
1. Flash your system with the new image, losing all your config.
2. Drop the kernel module into your existing system.

This guide will show you how to accomplish step 2, with the appropriate version. We will build for Ubilinux (`3.10.17-yocto-standard-r2`) in this example.

1. Edit the kernel recipe:

	```bash
	vi ~/edison-src/meta-intel-edison/meta-intel-edison-bsp/recipes-kernel/linux/linux-yocto_3.10.bbappend
	```

	Add the following:

	```bash
	LINUX_VERSION_EXTENSION = "-yocto-standard-r2"
	```

	This will overwrite the `CONFIG_LOCALVERSION=` inside of the kernel's `.config` file.

2. Change directories to the root of the source:
	
	```bash
	cd ~/edison-src/
	```
3. Run the make command:

	```bash
	make
	```

	This is important because bitbaking this way will clean up the bitbake configuration and will bitbake the modules/kernel with the version change. If you just run bitbake like normal, it won't see the version change and won't do anything.

4. Copy the module to your home directory:

	```bash
	cd ~/edison-src/out/current/build/tmp/work/edison-poky-linux/edison-image/1.0-r0/rootfs/lib/modules/
	```

	Now that you are here, do an `ls` to check the kernel version. It should be '*-yocto-standard-r2'

	```bash
	$ ls
	3.10.17-yocto-standard-r2
	```

	Copy the new module to your home directory (it might be nice to append the module name with the version):

	```bash
	cp 3.10.17-yocto-standard-r2/kernel/drivers/net/usb/smsc95xx.ko ~/smsc95xx.ko.3.10.17-yocto-standard-r2
	```

5. Follow the module installation instructions [here](installation.md).

--------------------------------------------------------------------

If you get this error message after dropping in your module, this means that you don't have the versions synced up correctly. Try carefully running through the steps in this guide again.

```bash
# insmod smsc95xx.ko
[  145.429168] smsc95xx: version magic '3.10.17-yocto-standard SMP preemt mod_unload ATOM ' should be '3.10.17-yocto-standard-rw SMP preemt mod_unload ATOM '
Error: could not insert module smsc95xx.ko: Invalid module format
# uname -r
3.10.17-yocto-standard-r2
```

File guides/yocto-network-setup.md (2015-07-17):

Setting up the Network Interface for Yocto
==========================================

This walks through assigning your LAN9512 an IP address and enabling ssh.

Follow these steps after `screen`'ing into your Edison from your host Linux machine, as described [here](https://software.intel.com/en-us/setting-up-serial-terminal-on-system-with-linux) (i.e., `sudo screen /dev/ttyUSB0 115200`).

1. Create an interfaces file for use with `ifup` and `ifconfig`. For a brief description of the `ifup` command, see [here](http://www.computerhope.com/unix/ifup.htm) or the man page.
	1. Create the `/etc/network` directory: `mkdir /etc/network`.
	2. Create the `/etc/network/interfaces` file: `touch /etc/network/interfaces`.
2. Find the name of the LAN9512 adapter. A very simple way is to use the `ifconfig` command with the `-a` flag to show all connected and disconnected interfaces. With the LAN9512 disconnected, run `ifconfig -a`. Then, connect the adapter and run `ifconfig -a` again. Note the name of the newly added interface. Mine was `enp0s17u1u1`.
	- For extra information, use the `dmesg` tool to view the kernel log and verify that the kernel found the device. You can run `dmesg | grep -i network` to find when the kernel recognized the network device, and when it gave it a name.
3. Edit the `/etc/network/interfaces` file and add the configuration: `vi /etc/network/interfaces`

	Add the following: *(be sure to double check the interface name)*
	```bash
	auto enp0s17u1u1
	iface enp0s17u1u1 inet dhcp
	```
4. Bring the network interface up with `ifup` and the interface name. Ignore any errors from `run-parts` about directories not existing.

	Run: `ifup enp0s17u1u1`
	This should tell you something about discovering the network interface and assigning it an IP address (using DHCP).

5. You can now test that your card is setup properly by running `ping xx.xx.xx.xx` on the Edison's IP address from your host Linux machine.

6. You must now either run `edison_configure --setup` but do not enable wifi. You will be asked to give a root password and name your Edison. If you do not provide a root password, you will have to edit the `/lib/systemd/system/sshd.socket` file, as shown below:

	*Allowing ssh without a root password:*
	```bash
	vi /lib/systemd/system/sshd.socket
	```

	In this file, comment out the line: `BindToDevice=usb0` using a `#`.

	Then reboot by running: `reboot`.

	(more info [here](https://communities.intel.com/message/254323#254323)).

7. You should now be able to ssh into your Edison!

	*Bonus:* Running `edison_configure` sets up your Edison to broadcast it's hostname, so instead of ssh'ing into your Edison's IP address, try using `<your hostname>.local`, e.g., `edison.local`

	**Known Issue:** For some reason, the Edison will not switch into USB Host mode except for every other reboot. Try doing a cold restart by unplugging and plugging power back in. (For more info, see [here](https://communities.intel.com/thread/57209?start=0&tstart=0))

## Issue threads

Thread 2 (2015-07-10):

Power board from Edison-Ethernet block

mountainraptor, 2015-07-10:
Being able to power the board via the Edison-Ethernet block would eliminate the need for the Base Block.  It may be nice to also add a FTDI chip on the Ethernet-Edison block.

asagraf, 2015-07-10:
It's worth noting that the board operating both its USB and Ethernet port at full capabilities draws very nearly the maximum current that the Edison can provide on its 3.3V rails. Adding an onboard power supply would allow us to design one with sufficient "breathing room."

Closed 2017-10-25.

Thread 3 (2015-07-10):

Board cannot accommodate Sparkfun base block

asagraf, 2015-07-10:
The board extends too far out its left (if viewed top-down with text facing upright) to accommodate a USB cable plugged into the Sparkfun Base Block if the Base Block is stacked directly on top of the Ethernet Block. Currently, an intermediary block (such as the GPIO block) must be stacked between thee two to facilitate plugging in a USB cable.

asagraf, 2015-07-10:
This could likely also be remedied by purchasing the larger-sized (taller) Hirose connectors, such as the ones Sparkfun uses, instead of the shorter size we have.

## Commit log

2015-05-29 Create Preliminary BOM
    Added preliminary BOM
2015-05-29 Delete Preliminary BOM
    Oops, I wanted to upload the file not like this.
2015-05-29 Create Preliminary BOM
    I can't create a repo to put it in so I'll just put it here. I'll most likely delete this and add the actual word document when I figure out how.
2015-05-29 Update Preliminary BOM
    Added Hirose connectors to BOM
2015-06-02 Added first revision of schematic and board. Board is not yet routed.
    [Board.brd, Board.sch]
2015-06-02 Changed LED from 0805 package to 0603 package
    [Board.brd, Board.sch]
2015-06-02 Rolled back previous change
    [Board.brd, Board.sch]
2015-06-02 Added preliminary BOM to go with Board Revision 1
    [bom_r1.xlsx]
2015-06-02 Changed the Name of the schematics to better match the BoM
    [Board_R1.brd, Board_R1.sch]
2015-06-02 Removed Old schematics
    [Board.brd, Board.sch]
2015-06-03 Updated schematic and BOM to Rev. 2. Removed one USB port and changed power delivery circuitry to downstream USB.
    [Board_R2.brd, Board_R2.sch, bom_r2.xlsx]
2015-06-03 Updated schematic and BOM to Rev. 2: Removed one USB and changed power supply circuitry for downstream USB. Removed old documents.
    [Board_R1.brd, Board_R1.sch, bom_r1.xlsx]
2015-06-04 Added intitial 4 layer board layout and made very minor changes to Schematic and BOM.
    [Board_R2.brd, Board_R2.sch, bom_r2.xlsx]
2015-06-05 Updated layout with better design rules, to match 4PCB.com
    [Board_4Layer_R2.brd]
2015-06-05 Finished first board layout Board_4layer_R2
    [Board_4Layer_R2.brd]
2015-06-08 Updated board and schematic as per recommendations.
    [Board_4Layer_R2.brd, Board_R2.sch, bom_r2.xlsx]
2015-06-08 Added PDF Schematic
2015-06-08 Removed olf board file, made some changes to new board file and schematic. BOM is till complete.
    [Board_4Layer_R2.brd, Board_R2.brd, Board_R2.sch]
2015-06-09 Revised board.
    [Board_4Layer_R2.brd]
2015-06-09 Updated BOM to reflect layout changes.
    [bom_r2.xlsx]
2015-06-09 Added "Reference" folder with board layout/schematic references.
2015-06-09 Added new reference material
2015-06-11 Board ready for manufacturing: Added mounting hardware and verified trace impedances. Designed to Advanced Circuit's specifications and passes their checks at FreeDFM.com.
    [Board_4Layer_R2.brd, Board_R2.sch]
2015-06-11 Updated BOM with qty and urls
    [bom_r2.xlsx]
2015-06-11 Updated BOM
    [bom_r2.xlsx]
2015-06-11 Updated board to final version and added CAM files.
    [Board_4Layer_R2.brd]
2015-06-11 updated config_mac to fix mount bug
2015-06-12 Fixed board inconsistencies, airwires, stubs, etc. Passes FreeDFM.com checks with no errors and warnings. Exported CAM files.
    [Board_4Layer_R2.brd]
2015-06-12 Minor changes
    [Board_4Layer_R2.brd]
2015-06-24 PoE and SD card added
    [Board_R2_v2.brd, Board_R2_v2.sch, PoE BOM.xlsx]
2015-06-24 Changed PoE module to accomodate USB_VBUS, changed Rectifiers, added level shifter
    [Board_R2_v2.brd, Board_R2_v2.sch, PoE BOM.xlsx]
2015-06-25 Tied DCIN to VSYS, added LED, cleaned up Bridge Rectifiers
    [Board_R2_v2.sch, PoE BOM.xlsx]
2015-06-26 Added R for min load
    [Board_R2_v2.sch, PoE BOM.xlsx]
2015-06-29 Added downstream USB through hirose, fixed some connections between top and bottom connectors
    [Board_R2_v2.sch, PoE BOM.xlsx]
2015-07-10 Updated BOM to include R17 - a minor oversight in the original BOM
    [bom_r2.xlsx]
2015-07-10 fixed BOM issue with 56kOhm vs. 56 ohm resistor (R15)
    [bom_r2.xlsx]
2015-07-17 PoE Board completed. Added Micro USB to schematic and board
    [Board_R2_v2.brd, PoE BOM.xlsx, PoE_Board.brd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]
2015-07-17 Fixed part labels, fixed a couple acute angles
    [PoE_Board.brd]
2015-07-17 Fixed some 45 degree angles
    [PoE_Board.brd]
2015-07-20 Fixed some stuff from DRC
    [PoE BOM.xlsx, PoE_Board.brd]
2015-07-20 Got rid of unrouted airwires
    [PoE_Board.brd]
2015-07-20 Connected shield pins on Ethernet jack
    [PoE_Board.brd]
2015-07-21 Moved U8 to top of board, moved LED1 from under the Edison, put C28 back on the bottom
    [PoE_Board.brd]
2015-07-21 Minor changes in via placement
    [PoE_Board.brd]
2015-07-24 Added smaller version of original board. Minor changes to PoE board
    [PoE_Board.brd, Small_Ethernet.brd, Small_Ethernet.sch]
2015-07-24 Added library file. Everything Chleo made & some devices from Sparkfun's libraries
2015-08-06 Added ground fills. PoE: power planes around U7, diode for power through microB. Small: changed C26 to 2 caps, removed NP caps, removed test points, replaced crystal
    [PoE BOM.xlsx, PoE_Board.sch, Small_Ethernet.brd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]
2015-08-07 Ready for final review
    [PoE_Board.brd, Small_Ethernet.brd]
2015-08-10 Updated library and BOM
    [PoE BOM.xlsx]
2015-08-10 Made downstream USB traces the same length; minor changes to PoE board
    [PoE_Board.brd, Small_Ethernet.brd]
2015-08-10 Fixed stub traces around Edison connector
    [PoE BOM.xlsx, PoE_Board.brd, Small_Ethernet.brd]
2015-08-17 Added LDO for power off VSYS (to ensure enough current to LAN); Added datasheets for LDO and FTDI chip
    [Small_Ethernet.brd, Small_Ethernet.sch, bom_v3.xlsx]
2015-08-17 Added LDO for power off VSYS, fixed SD card
    [PoE BOM.xlsx, PoE_Board.brd, PoE_Board.sch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]
2015-08-18 Changed R20
    [PoE BOM.xlsx, PoE_Board.brd, PoE_Board.sch]
2015-08-19 Aesthetic changes for Ryan
    [PoE_Board.brd, Small_Ethernet.brd]

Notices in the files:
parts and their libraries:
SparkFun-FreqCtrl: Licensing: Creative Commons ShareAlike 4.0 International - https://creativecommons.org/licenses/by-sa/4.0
